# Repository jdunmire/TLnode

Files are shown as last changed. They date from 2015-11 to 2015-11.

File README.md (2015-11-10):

Temperature and Light Sensor Node
=================================
This a [KiCad](http://kicad-pcb.org/) design. The node measures
temperature and light levels. It is battery powered and uses the
ESP-8266 module for networking.

Additional information about this node can be found at the 
[Sensor Nodes](http://sensornodeinfo.rockingdlabs.com) website.

Copyright Jerry Dunmire 2015.

This documentation describes Open Hardware and is licensed under the
CERN OHL v. 1.2.

You may redistribute and modify this documentation under the terms of
the CERN OHL v.1.2. (LICENSE.txt). This documentation is distributed
WITHOUT ANY EXPRESS OR IMPLIED WARRANTY, INCLUDING OF MERCHANTABILITY,
SATISFACTORY QUALITY AND FITNESS FOR A PARTICULAR PURPOSE. Please see
the CERN OHL v.1.2 for applicable conditions

Guidelines on how to apply the CERN OHL v1.2 are in the
cern_ohl_v_1_2_howto.pdf file.

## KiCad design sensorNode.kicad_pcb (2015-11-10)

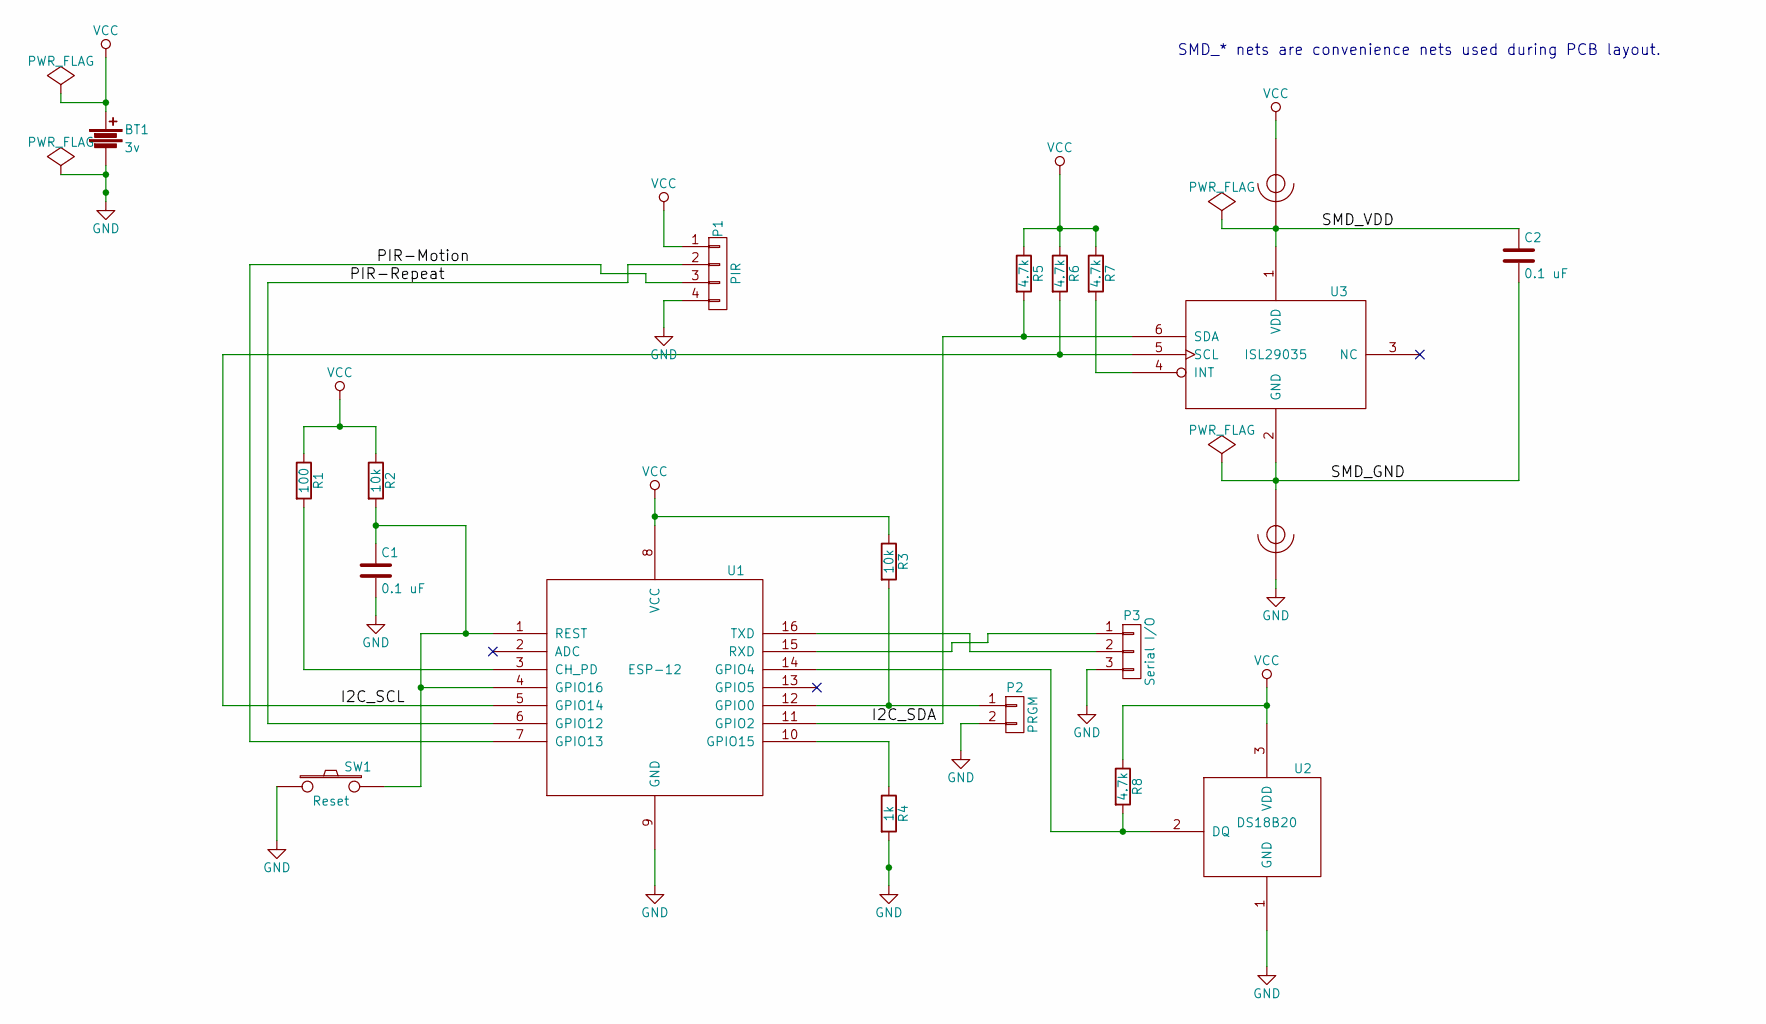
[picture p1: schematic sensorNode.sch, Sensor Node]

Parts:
BT1: 3v; BA2AAPC
C1, C2: 0.1 uF; C_0603_HandSoldering
NT1, NT2: Net-Tie-2; NetTie-I_Connected_SMD
P1: PIR; Pin_Header_Angled_1x04
P2: PRGM; Pin_Header_Angled_1x02
P3: Serial I/O; Pin_Header_Angled_1x03
R1: 100; R_0603_HandSoldering
R2, R3: 10k; R_0603_HandSoldering
R4: 1k; R_0603_HandSoldering
R5, R6, R7, R8: 4.7k; R_0603_HandSoldering
SW1: Reset; SW_SPST_E-Switch_TL3302BF180QG
U1: ESP-12
U2: DS18B20; TO-92_Inline_Narrow_Oval
U3: ISL29035; DFN-6_1.5x1.6mm_Pitch0.5mm

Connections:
/I2C_SCL: R6.2, U1.5 (GPIO14), U3.5 (SCL)
/I2C_SDA: R5.2, U1.11 (GPIO2), U3.6 (SDA)
/PIR-Motion: P1.3, U1.7 (GPIO13)
/PIR-Repeat: P1.2, U1.6 (GPIO12)
/SMD_GND: C2.2, NT2.1, U3.2 (GND)
/SMD_VDD: C2.1, NT1.2, U3.1 (VDD)
GND: BT1.2, C1.2, NT2.2, P1.4, P2.2, P3.3, R4.2, SW1.1, U1.9 (GND), U2.1 (GND)
unnamed: C1.1, R2.2, SW1.2, U1.1 (REST), U1.4 (GPIO16)
unnamed: P2.1, R3.2, U1.12 (GPIO0)
unnamed: P3.1, U1.15 (RXD)
unnamed: P3.2, U1.16 (TXD)
unnamed: R1.2, U1.3 (CH_PD)
unnamed: R4.1, U1.10 (GPIO15)
unnamed: R7.2, U3.4 (INT)
unnamed: R8.2, U1.14 (GPIO4), U2.2 (DQ)
VCC: BT1.1, NT1.1, P1.1, R1.1, R2.1, R3.1, R5.1, R6.1, R7.1, R8.1, U1.8 (VCC), U2.3 (VDD)

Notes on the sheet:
SMD_* nets are convenience nets used during PCB layout.

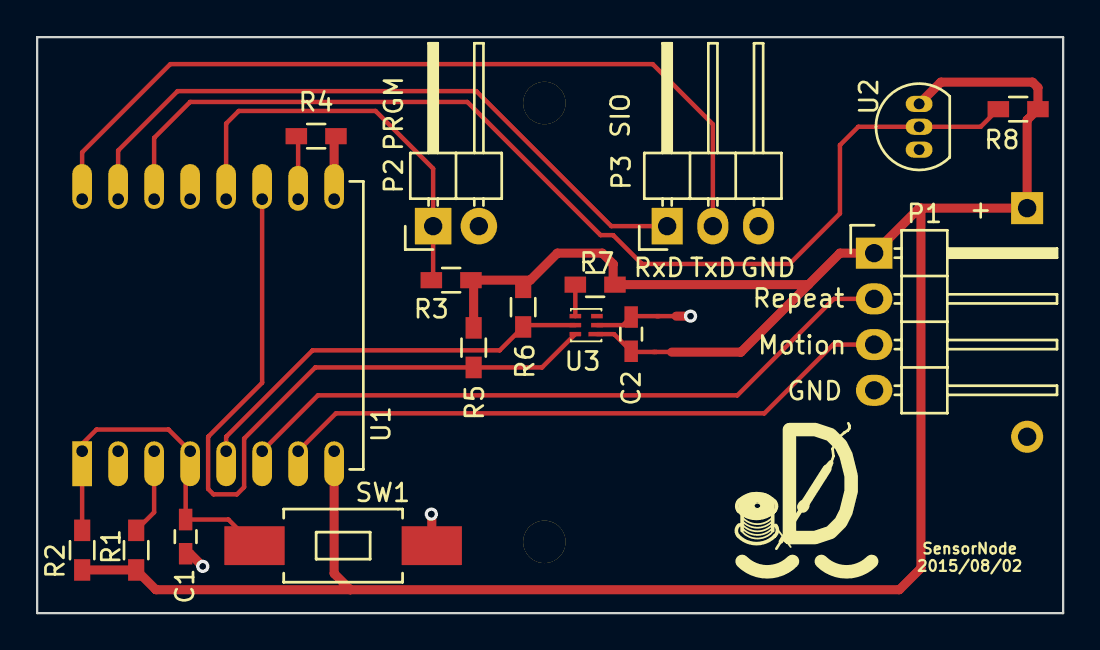
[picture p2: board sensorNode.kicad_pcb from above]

Board: 2 copper layers, 57.0 x 32.0 mm, 20 parts (1 on the bottom side), 16 nets.

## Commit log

2015-05-21 Initial commit - schematic complete for now
    On branch master
    new file: .gitignore
    new file: CAM/README.md
    new file: rockingdlabs_letter_with_logo.kicad_wks
    new file: sensorNode-cache.lib
    new file: sensorNode.kicad_pcb
    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
    [sensorNode.kicad_pcb, sensorNode.sch]
2015-05-21 update netlist
    modified: sensorNode.net
    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
2015-05-21 Placed with 1206 parts
    No routing attempted.
    Battery is wrong.
    Board outline is crude approximation of battery holder
    new file: sensorNode.cmp
    modified: sensorNode.kicad_pcb
    modified: sensorNode.sch
    new file: sensorNode.xml
    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
    [sensorNode.kicad_pcb, sensorNode.sch]
2015-05-24 Multiple changes
    - Add bypass cap for isl29035
    - Update footprints for battery and isl29035
    - place parts on pcb
    - possibly others
    new file: fp-lib-table
    modified: sensorNode.cmp
    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
    [sensorNode.kicad_pcb, sensorNode.sch]
2015-05-24 Route signals and VCC
    Ground plane needs to be added. Two design rule errors for U3 due
    to design rule settings, not real limits.
    A better switch solution would be preferred, having to connect all pins
    and not being able to use common pins as jumpers made routing a lot more
    difficult.
    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
    [sensorNode.kicad_pcb]
2015-05-24 Add ground plane
    Complete routing. Two design error reported due to default and VCC
    design rule conflict with U3 pad spacing.
    Missing 3d models for switch and ESP8320
    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
    [sensorNode.kicad_pcb]
2015-05-30 Remove previous PCB files
    On branch newPCB
    deleted: sensorNode.cmp
    deleted: sensorNode.kicad_pcb
    deleted: sensorNode.net
    [sensorNode.kicad_pcb]
2015-05-30 Add net-tie to divide pwr nets for routing
    modified: sensorNode-cache.lib
    new file: sensorNode.net
    modified: sensorNode.pro
    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
    [sensorNode.sch]
2015-05-30 Assign packages
    Net-ties and 2-pin button are new.
    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
2015-05-31 Check-point: components placed
    Schematic was modified to swap signals on connector pins
    to make routing easier.
    modified: rockingdlabs_letter_with_logo.kicad_wks
    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
    [sensorNode.kicad_pcb, sensorNode.sch]
2015-05-31 Routing complete
    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
    [sensorNode.kicad_pcb]
2015-07-01 Add labels on silkscreen
    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
    [sensorNode.kicad_pcb]
2015-08-02 Add script to generate BOM
    new file: bom2csv_tabs.xsl
    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
2015-08-02 Add part details for BOM
    modified: sensorNode.xml
    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
    [sensorNode.kicad_pcb, sensorNode.sch]
2015-08-02 Use ESP-12 footprint with smaller silkscreen
    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
    [sensorNode.kicad_pcb]
2015-08-02 Use batter holder with outline on comments layer
    If outline was left on the silkscreen, the board size would
    have to be larger.
    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
    [sensorNode.kicad_pcb]
2015-08-02 Rotate logo on bottom
    new file: CAM/.gitignore
    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
    [sensorNode.kicad_pcb]
2015-11-10 Add version info
    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
    [sensorNode.sch]

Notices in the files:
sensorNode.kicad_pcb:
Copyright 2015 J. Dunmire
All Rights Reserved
